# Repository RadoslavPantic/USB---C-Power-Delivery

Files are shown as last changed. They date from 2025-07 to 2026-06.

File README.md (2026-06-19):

# 100W USB-C Power Delivery Module

A high-power USB-C Power Delivery (PD) module capable of delivering up to **100W (20V @ 5A)**. 

---

## Project Contents

This repository includes:
- KiCad design files (`.kicad_pro`, `.kicad_pcb`, `.kicad_sch`)
- **Gerber files** for PCB fabrication
- **BOM** file (`usb_c_pd_source.csv`)

---

## Description

The project is based around the STUSB4710 Autonomous USB PD controller IC. The design functions as a power source with short-circuit protection and Vbus monitoring.
The project is configured in a buck topology, meaning there is a constant 24 V DC voltage at the input of the circuit. Using the TPS56837HRPAR buck converter, the PD IC sets the output USB-C compliant voltage. The project is hardware-heavy — the MCU is only needed to monitor the buck converter and to increase the current on the 20 V PDO from 2.25 A to 5 A

## Schematic

The schematic of the circuit is shown below:

Schematic

---

## 3D View

The 3D render of the assembled PCB:

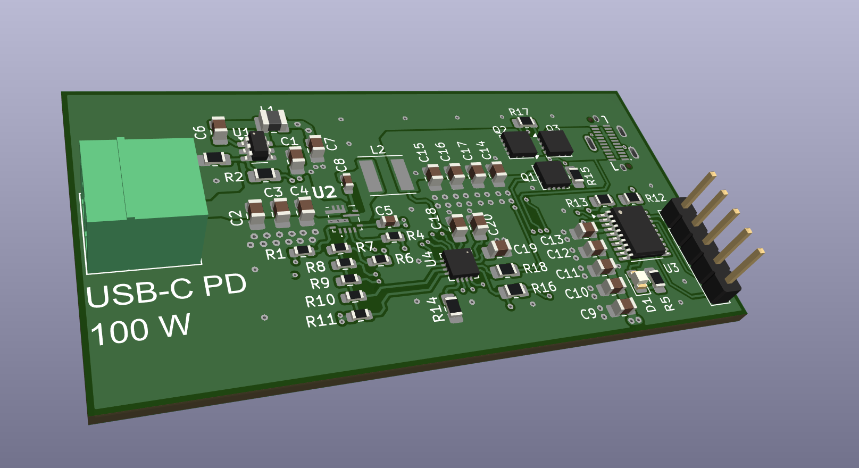
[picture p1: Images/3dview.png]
3D View


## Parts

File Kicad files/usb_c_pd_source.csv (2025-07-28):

Reference | Qty | Value | DNP | Exclude from BOM | Exclude from Board | Footprint | Datasheet
U4 | 1 | STUSB4710AQ1TR |  |  |  | Package_DFN_QFN:QFN-16-1EP_3x3mm_P0.5mm_EP1.7x1.7mm | https://eu.mouser.com/datasheet/2/389/stusb4710-1852079.pdf
U3 | 1 | STM32G030F6Px |  |  |  | Package_SO:TSSOP-20_4.4x6.5mm_P0.65mm | https://www.st.com/resource/en/datasheet/stm32g030f6.pdf
U2 | 1 | TPS56837HRPAR |  |  |  | footprints:TPS56A37RPAR | https://www.ti.com/lit/ds/symlink/tps56837h.pdf?ts=1746769281785
U1 | 1 | TPS560430X3FDBVR |  |  |  | Package_TO_SOT_SMD:SOT-23-6 | https://www.ti.com/lit/ds/symlink/tps560430.pdf?ts=1747035398395
R18 | 1 | 2k2 |  |  |  | Resistor_SMD:R_0805_2012Metric_Pad1.20x1.40mm_HandSolder | ~
R15 | 1 | 820R |  |  |  | Resistor_SMD:R_0805_2012Metric_Pad1.20x1.40mm_HandSolder | ~
R11 | 1 | 1.95k |  |  |  | Resistor_SMD:R_0805_2012Metric_Pad1.20x1.40mm_HandSolder | ~
R10 | 1 | 570R |  |  |  | Resistor_SMD:R_0805_2012Metric_Pad1.20x1.40mm_HandSolder | ~
R9 | 1 | 340R |  |  |  | Resistor_SMD:R_0805_2012Metric_Pad1.20x1.40mm_HandSolder | ~
R8 | 1 | 310R |  |  |  | Resistor_SMD:R_0805_2012Metric_Pad1.20x1.40mm_HandSolder | ~
R7 | 1 | 930R |  |  |  | Resistor_SMD:R_0805_2012Metric_Pad1.20x1.40mm_HandSolder | ~
R6 | 1 | 30k |  |  |  | Resistor_SMD:R_0805_2012Metric_Pad1.20x1.40mm_HandSolder | ~
R5,R12,R13 | 3 | 1k7 |  |  |  | Resistor_SMD:R_0805_2012Metric_Pad1.20x1.40mm_HandSolder | ~
R4,R14 | 2 | 100k |  |  |  | Resistor_SMD:R_0805_2012Metric_Pad1.20x1.40mm_HandSolder | ~
R3 | 1 | 22.1k |  |  |  | Resistor_SMD:R_0805_2012Metric_Pad1.20x1.40mm_HandSolder | ~
R2 | 1 | 51k |  |  |  | Resistor_SMD:R_0805_2012Metric_Pad1.20x1.40mm_HandSolder | ~
R1,R16,R17 | 3 | 10k |  |  |  | Resistor_SMD:R_0805_2012Metric_Pad1.20x1.40mm_HandSolder | ~
Q1,Q2,Q3 | 3 | DMP3013SFV-7 |  |  |  | Package_SON:Diodes_PowerDI3333-8 | https://eu.mouser.com/datasheet/2/115/DIOD_S_A0008513542_1-2543083.pdf
NT1 | 1 | NetTie_2 |  | Excluded from BOM |  | NetTie:NetTie-2_SMD_Pad0.5mm | ~
L2 | 1 | 4.7u |  |  |  | footprints:INDPM112100X400N | https://eu.mouser.com/datasheet/2/210/WLPMA0A040LC_Series-1670480.pdf
L1 | 1 | 12u |  |  |  | footprints:SRR0735A120M | https://eu.mouser.com/datasheet/2/54/SRR0735A-1391425.pdf
J4 | 1 | USB4151-GF-C |  |  |  | footprints:USB4151GFC | https://eu.mouser.com/datasheet/2/837/GCT_USB4151-3240033.pdf
J3 | 1 | Serial Wire |  |  |  | Connector_PinHeader_2.54mm:PinHeader_1x05_P2.54mm_Vertical | ~
J2 | 1 | Lab_supply |  |  |  | Connector_Phoenix_MC:PhoenixContact_MC_1,5_2-G-3.5_1x02_P3.50mm_Horizontal | ~
J1 | 1 | Barrel_Jack |  |  |  | footprints:PJ106AHTR | ~
D1 | 1 | LED |  |  |  | LED_SMD:LED_0805_2012Metric | ~
C18,C19,C20 | 3 | 1u |  |  |  | Capacitor_SMD:C_0805_2012Metric_Pad1.18x1.45mm_HandSolder | ~
C10,C11,C12,C13 | 4 | 100n |  |  |  | Capacitor_SMD:C_0805_2012Metric_Pad1.18x1.45mm_HandSolder | ~
C7,C14,C15,C16,C17 | 5 | 22u |  |  |  | Capacitor_SMD:C_0805_2012Metric_Pad1.18x1.45mm_HandSolder | ~
C5 | 1 | 22n |  |  |  | Capacitor_SMD:C_0805_2012Metric_Pad1.18x1.45mm_HandSolder | ~
C4,C6,C8 | 3 | 0.1u |  |  |  | Capacitor_SMD:C_0805_2012Metric_Pad1.18x1.45mm_HandSolder | ~
C2,C3,C9 | 3 | 10u |  |  |  | Capacitor_SMD:C_0805_2012Metric_Pad1.18x1.45mm_HandSolder | ~
C1 | 1 | 2.2u |  |  |  | Capacitor_SMD:C_0805_2012Metric_Pad1.18x1.45mm_HandSolder | ~

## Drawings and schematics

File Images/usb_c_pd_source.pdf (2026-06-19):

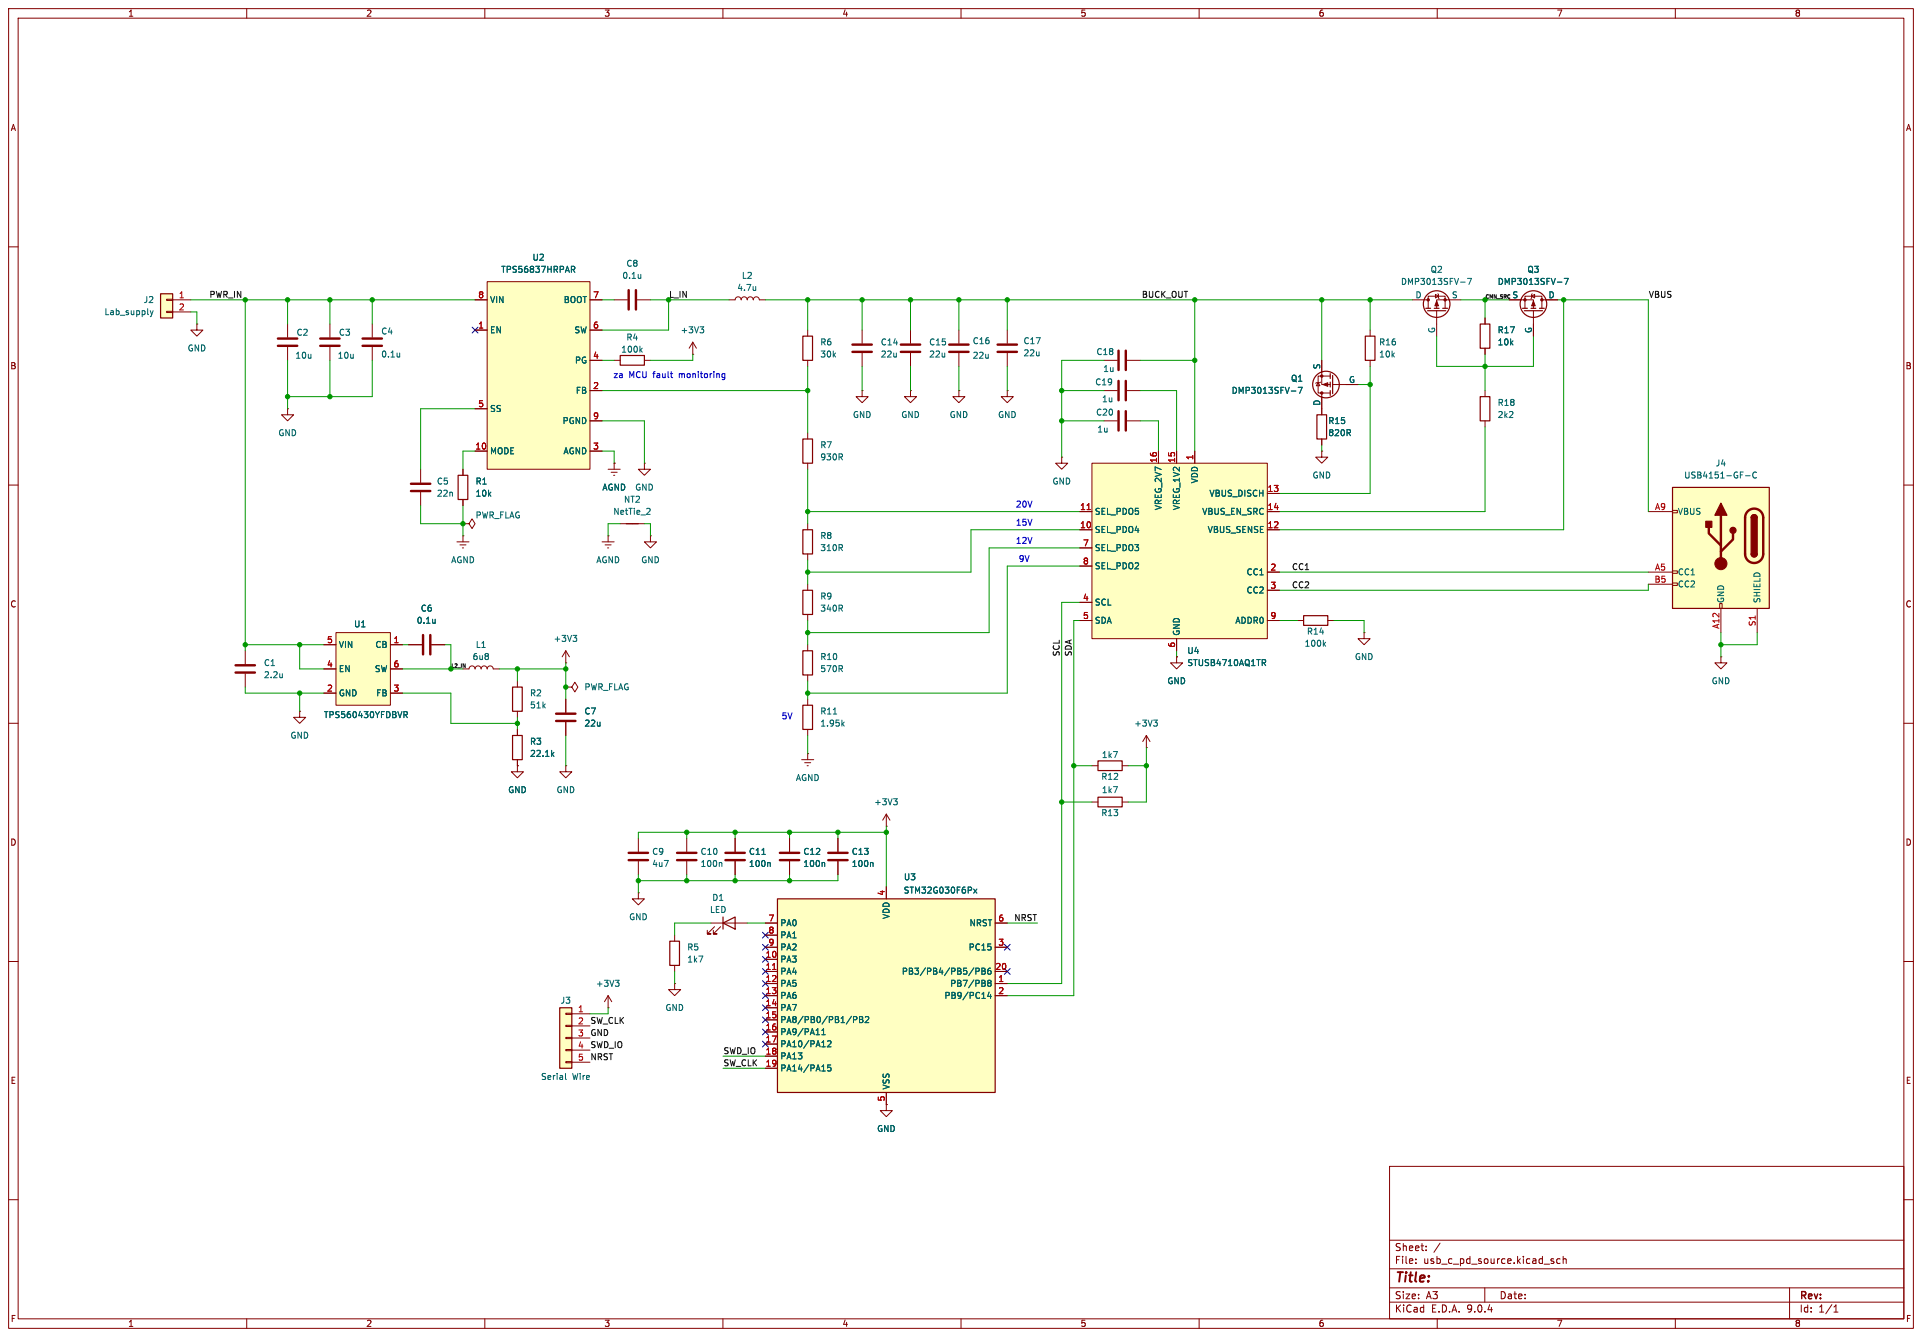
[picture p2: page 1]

Id: 1/1 Title: File: usb_c_pd_source.kicad_sch Sheet: /

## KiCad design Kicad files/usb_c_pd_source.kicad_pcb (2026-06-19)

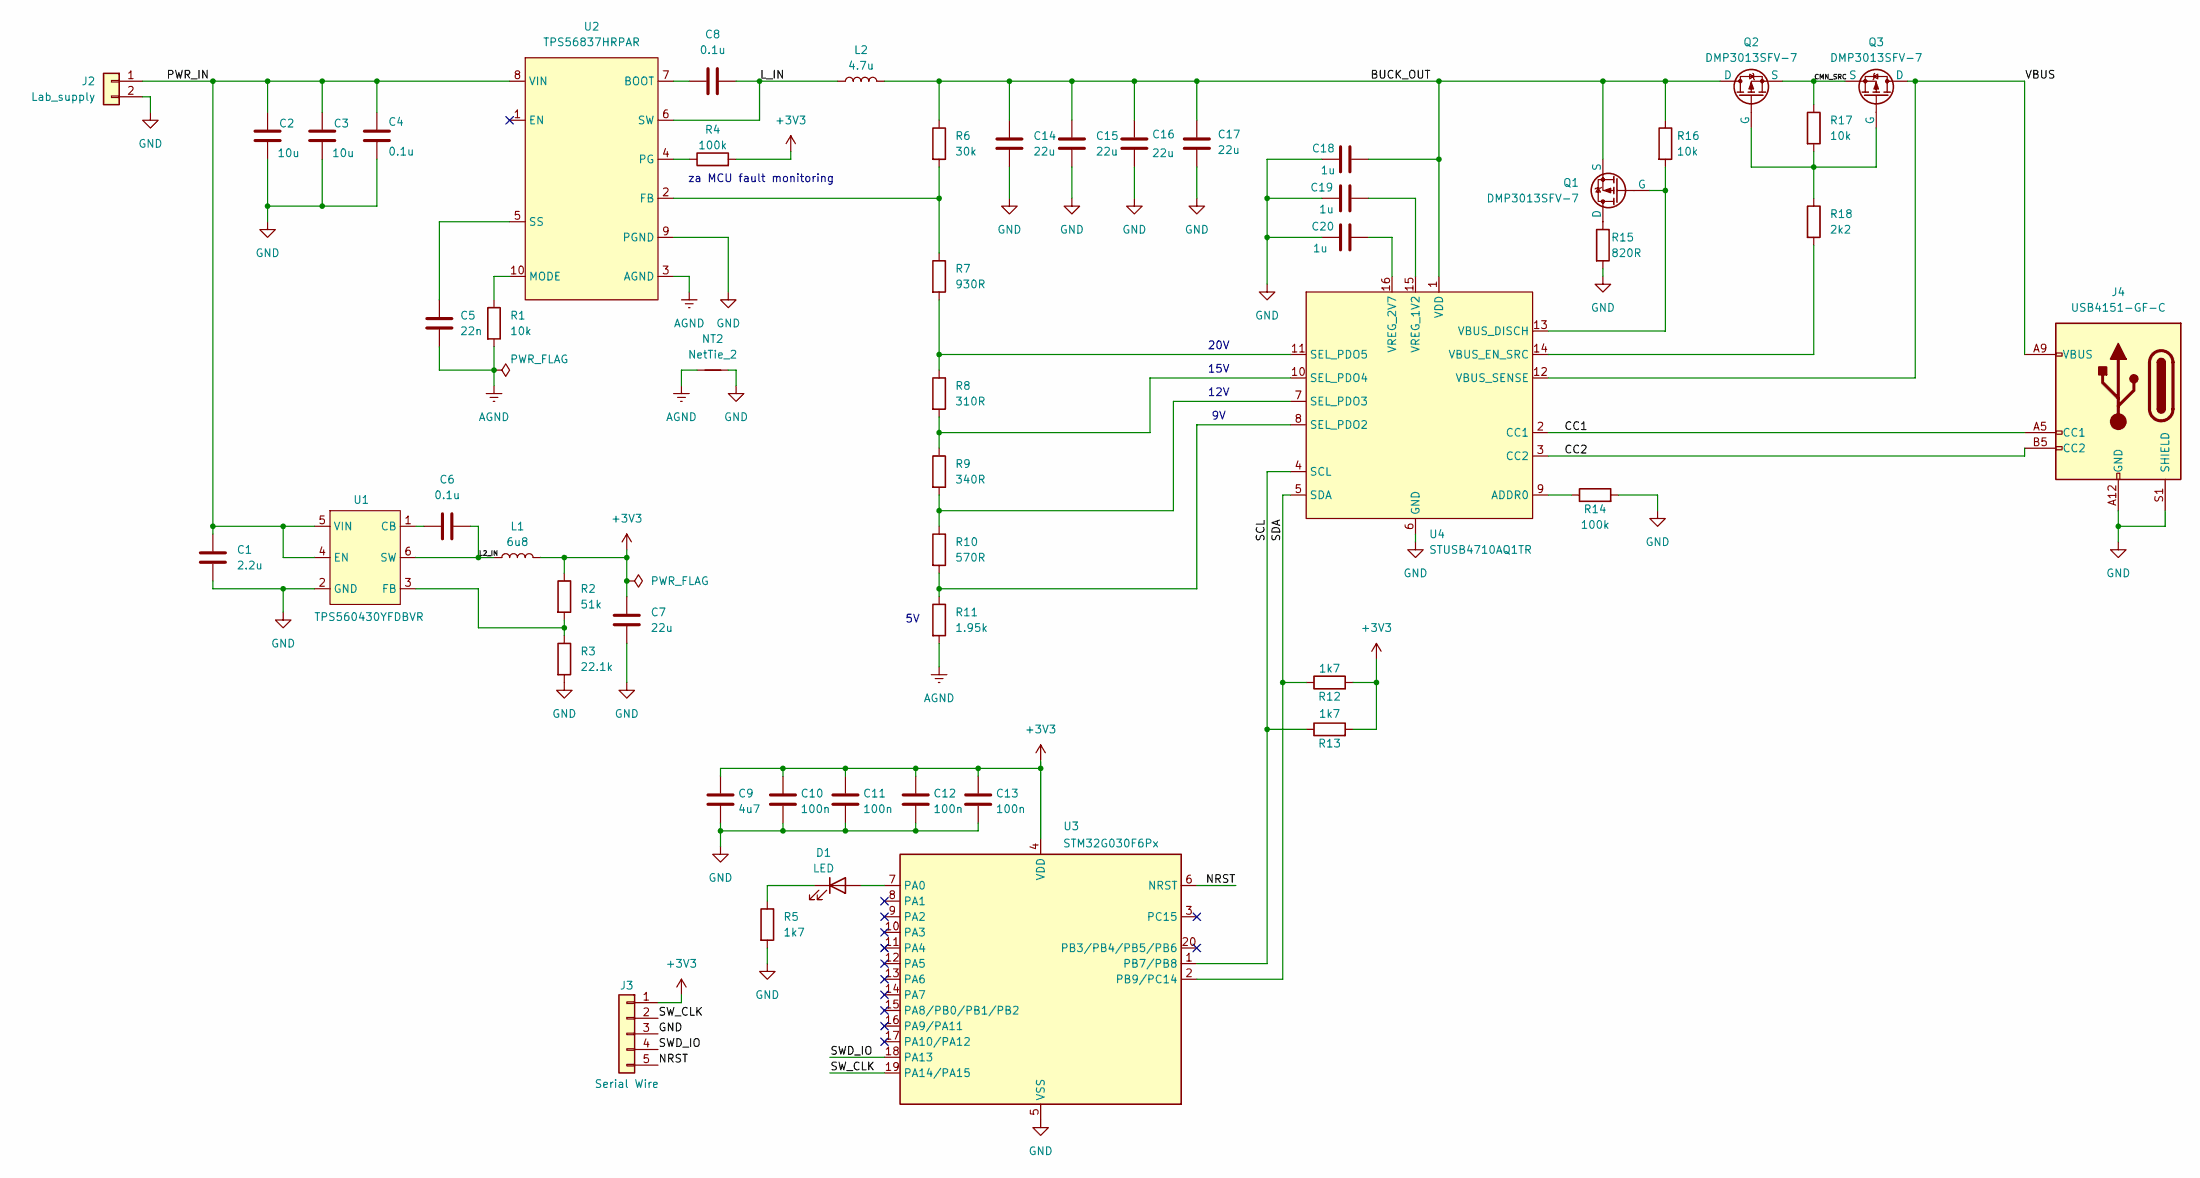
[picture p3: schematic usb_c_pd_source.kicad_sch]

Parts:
C1: 2.2u; C_0805_2012Metric_Pad1.18x1.45mm_HandSolder
C2, C3: 10u; C_0805_2012Metric_Pad1.18x1.45mm_HandSolder
C4, C6: 0.1u; C_0805_2012Metric_Pad1.18x1.45mm_HandSolder
C5: 22n; C_0603_1608Metric
C7, C14, C15, C16, C17: 22u; C_0805_2012Metric_Pad1.18x1.45mm_HandSolder
C8: 0.1u; C_0603_1608Metric
C9: 4u7; C_0805_2012Metric_Pad1.18x1.45mm_HandSolder
C10, C11, C12, C13: 100n; C_0805_2012Metric_Pad1.18x1.45mm_HandSolder
C18, C19, C20: 1u; C_0805_2012Metric_Pad1.18x1.45mm_HandSolder
D1: LED; LED_0805_2012Metric
J2: Lab_supply; PhoenixContact_MC_1,5_2-G-3.5_1x02_P3.50mm_Horizontal
J3: Serial Wire; PinHeader_1x05_P2.54mm_Vertical
J4: USB4151-GF-C; USB4151GFC
L1: 6u8; L_1008_2520Metric
L2: 4.7u; L_Taiyo-Yuden_MD-5050
NT2: NetTie_2; NetTie-2_SMD_Pad0.5mm
Q1, Q2, Q3: DMP3013SFV-7; Diodes_PowerDI3333-8
R1: 10k; R_0603_1608Metric
R2: 51k; R_0805_2012Metric_Pad1.20x1.40mm_HandSolder
R3: 22.1k; R_0805_2012Metric_Pad1.20x1.40mm_HandSolder
R4: 100k; R_0603_1608Metric
R5, R12, R13: 1k7; R_0805_2012Metric_Pad1.20x1.40mm_HandSolder
R6: 30k; R_0603_1608Metric
R7: 930R; R_0603_1608Metric
R8: 310R; R_0603_1608Metric
R9: 340R; R_0603_1608Metric
R10: 570R; R_0603_1608Metric
R11: 1.95k; R_0603_1608Metric
R14: 100k; R_0805_2012Metric_Pad1.20x1.40mm_HandSolder
R15: 820R; R_0805_2012Metric_Pad1.20x1.40mm_HandSolder
R16, R17: 10k; R_0805_2012Metric_Pad1.20x1.40mm_HandSolder
R18: 2k2; R_0805_2012Metric_Pad1.20x1.40mm_HandSolder
U1: TPS560430YFDBVR; SOT-23-6
U2: TPS56837HRPAR; TPS56A37RPAR
U3: STM32G030F6Px; TSSOP-20_4.4x6.5mm_P0.65mm
U4: STUSB4710AQ1TR; QFN-16-1EP_3x3mm_P0.5mm_EP1.7x1.7mm

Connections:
+3V3: C7.2, C9.1, C10.1, C11.1, C12.1, C13.1, J3.1, L1.2, R2.1, R4.2, R12.2, R13.2, U3.4 (VDD)
/BUCK_OUT: C14.2, C15.2, C16.2, C17.2, C18.2, L2.2, Q1.1 (S), Q1.2 (S), Q1.3 (S), Q2.5 (D), R6.1, R16.1, U4.1 (VDD)
/CC1: J4.A5 (CC1), U4.2 (CC1)
/CC2: J4.B5 (CC2), U4.3 (CC2)
/CMN_SRC: Q2.1 (S), Q2.2 (S), Q2.3 (S), Q3.1 (S), Q3.2 (S), Q3.3 (S), R17.1
/L2_IN: C6.2, L1.1, U1.6 (SW)
/L_IN: C8.1, L2.1, U2.6 (SW)
/NRST: J3.5, U3.6 (NRST)
/PWR_IN: C1.1, C2.1, C3.1, C4.1, J2.1, U1.4 (EN), U1.5 (VIN), U2.8 (VIN)
/SCL: R13.1, U3.1 (PB7/PB8), U4.4 (SCL)
/SDA: R12.1, U3.2 (PB9/PC14), U4.5 (SDA)
/SWD_IO: J3.4, U3.18 (PA13)
/SW_CLK: J3.2, U3.19 (PA14/PA15)
/VBUS: J4.A4 (VBUS), J4.A9 (VBUS), J4.B4 (VBUS), J4.B9 (VBUS), Q3.5 (D), U4.12 (VBUS_SENSE)
AGND: C5.2, NT2.1, R1.2, R11.2, U2.3 (AGND)
GND: C1.2, C2.2, C3.2, C4.2, C7.1, C9.2, C10.2, C11.2, C12.2, C13.2, C14.1, C15.1, C16.1, C17.1, C18.1, C19.1, C20.1, J2.2, J3.3, J4.A1 (GND), J4.A12 (GND), J4.B1 (GND), J4.B12 (GND), J4.S1 (SHIELD), NT2.2, R3.2, R5.2, R14.2, R15.2, U1.2 (GND), U2.9 (PGND), U3.5 (VSS), U4.6 (GND)
unnamed: D1.2 (A), U3.7 (PA0)
unnamed: D1.1 (K), R5.1
unnamed: Q1.5 (D), R15.1
unnamed: Q1.4 (G), R16.2, U4.13 (VBUS_DISCH)
unnamed: Q2.4 (G), Q3.4 (G), R17.2, R18.1
unnamed: C6.1, U1.1 (CB)
unnamed: R2.2, R3.1, U1.3 (FB)
unnamed: C8.2, U2.7 (BOOT)
unnamed: R6.2, R7.1, U2.2 (FB)
unnamed: R1.1, U2.10 (MODE)
unnamed: R4.1, U2.4 (PG)
unnamed: C5.1, U2.5 (SS)
unnamed: R14.1, U4.9 (ADDR0)
unnamed: R10.2, R11.1, U4.8 (SEL_PDO2)
unnamed: R9.2, R10.1, U4.7 (SEL_PDO3)
unnamed: R8.2, R9.1, U4.10 (SEL_PDO4)
unnamed: R7.2, R8.1, U4.11 (SEL_PDO5)
unnamed: R18.2, U4.14 (VBUS_EN_SRC)
unnamed: C19.2, U4.15 (VREG_1V2)
unnamed: C20.2, U4.16 (VREG_2V7)

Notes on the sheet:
15V
12V
za MCU fault monitoring
20V

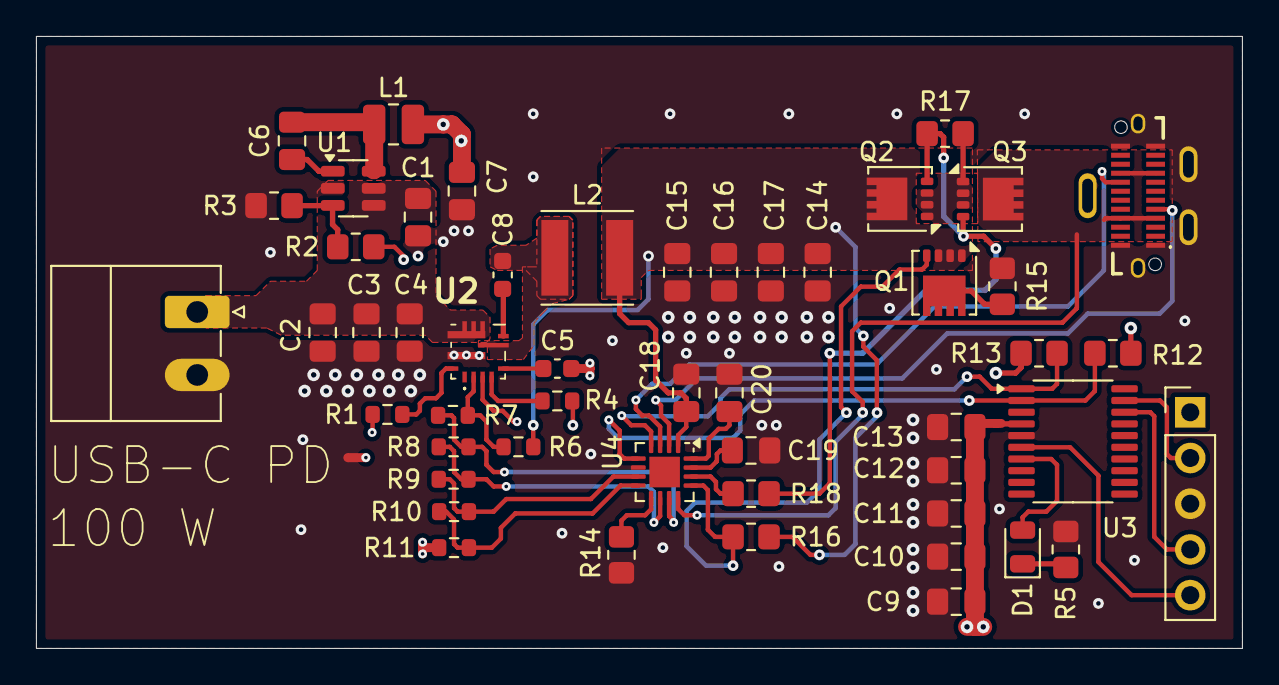
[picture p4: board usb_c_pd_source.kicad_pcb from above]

Board: 4 copper layers, 67.0 x 34.0 mm, 52 parts (0 on the bottom side), 36 nets.
